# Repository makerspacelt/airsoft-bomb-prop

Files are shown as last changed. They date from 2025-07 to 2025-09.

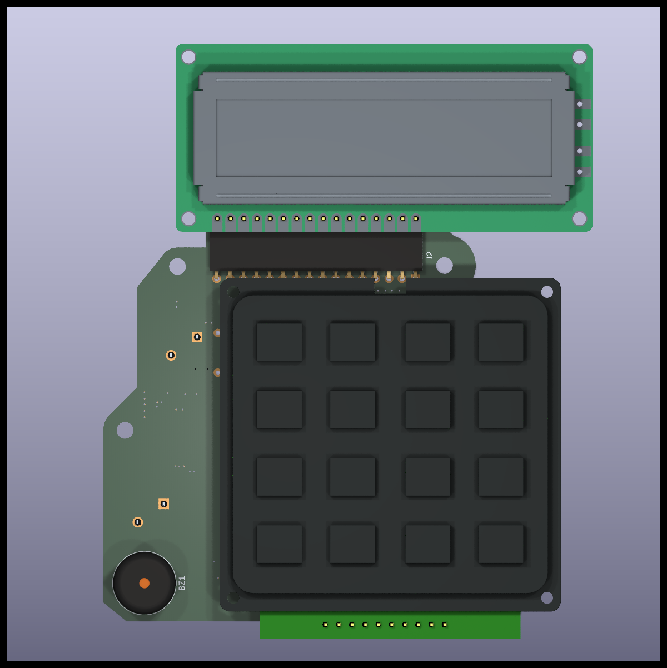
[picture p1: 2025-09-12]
hw/gen/img_pcb_3d_front.png

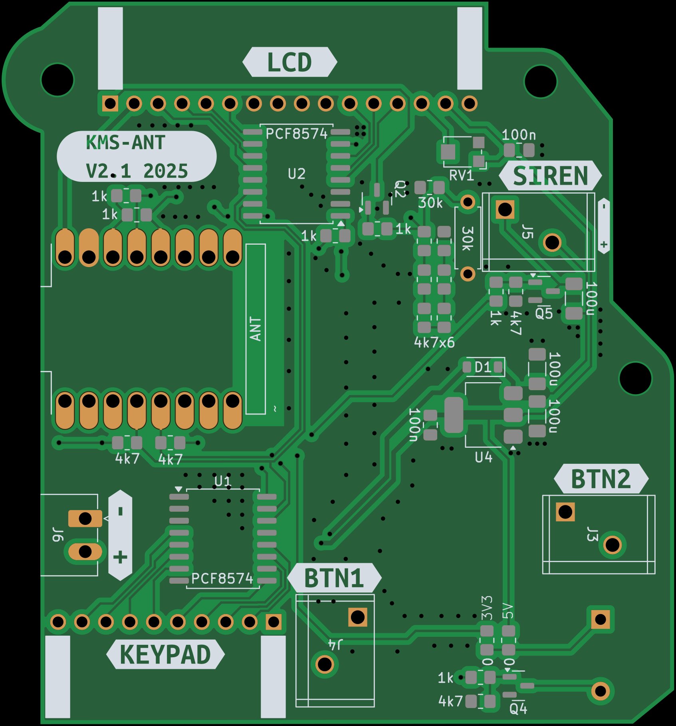
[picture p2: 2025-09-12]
hw/gen/img_pcb_2d_back_bare.jpg

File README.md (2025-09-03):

This is the source code of an Airsoft prop [KMS-ANT](http://armory.makerspace.lt) designed and sold by [Kaunas Makerspace](https://makerspace.lt).

This repository contains:

* [sw/](/sw) - ESPHome-based C++ software licensed under [GPL-3.0](/sw/LICENSE)
* [hw/](/hw) - PCB designed using KiCad and licensed under [CERN-OHL-S](/hw/LICENSE)

You can buy the product here: https://www.tindie.com/products/makerspacelt/airsoft-bomb-prop-kms-ant/

More information: http://armory.makerspace.lt/

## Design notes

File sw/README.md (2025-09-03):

This is the source code of an Airsoft prop [KMS-ANT](http://armory.makerspace.lt) designed and sold by [Kaunas Makerspace](https://makerspace.lt).

The code is licensed under GPL-3. If you modify this code and distribute it, then you are required to publish your changes under GPL-3 license as well.

# Building

```sh
# Build and flash esphome firmware, then open log monitoring
# (requires docker or podman for esphome)
$ make flash DEVICE=/dev/ttyACM0

# Build esphome firmware
# (requires docker or podman for esphome)
$ make fw

# Compile the pc build and run integration tests
# (requires the g++ compiler)
$ make test

# Compile the pc build and run it in interactive mode
# (requires the g++ compiler)
$ make interact

# Format project's C++ code using clang-format
# (requires the clang-format utility)
$ make format
```

# Code Structure

```
src-common/                → Shared code used across all platforms (ESP32 & PC)
  ├── utilities.hpp/cpp    → Helper functions (e.g., formatting time, progress bars)
  ├── globals.hpp          → Constants, key definitions, and global state (AntGlobals)
  ├── gm_*.hpp             → Game mode classes (each game is its own class)
  ├── gm_manager.hpp       → Main controller: manages game modes & user input.

src-pc/                    → PC-only code to simulate the game (for development/debugging)
  ├── main.cpp             → Entry point: runs interactive mode & test sequences
  └── mock_esphome.hpp     → Simulates ESP32 hardware (LCD, buttons, millis)

src-esphome/               → ESPHome firmware config
```

* All hardware is managed by [ESPHome](https://esphome.io/components/), as defined in `src-esphome/config.yaml`.
* All game logic is implemented in C++ in `src-common/*`.
* The game logic code communicates with ESPHome through globals, as defined in `src-esphome/esphome-entry.hpp`.
* There is a PC build for interactive and automated testing.

Normally in ESPHome you can call custom C++ code from lambdas defined in
`config.yaml` or from included C++ files. But calling ESPHome functions from
your custom C++ code is unsupported. So we try to keep this interaction to a
minimum. When we need to activate some hardware, we set an action state bitmask
(as defined in `src-common/globals.hpp`), then in ESPHome code we checked,
executed and reset the action state.

Game modes are implemented as classes with the following interface:
```cpp
class GameModeX {
public:
  // Constructor expects `AntGlobals antg` global state.
  AntGlobals &antg;
  GameModeX(AntGlobals &antg) : antg(antg) {}

  // Reset state and prepare for a new game.
  void init();

  // Render current game state to LCD.
  void display_update(esphome::lcd_base::LCDDisplay &disp);

  // Process user input and update game logic.
  void handle_key(unsigned char key);

  // Update time-based logic (timers, progress, events).
  void clock(uint32_t now, uint32_t delta);
};
```

# Tests

There is a custom test runner `src-pc/tests/test.sh` which executes all tests
defined in `src-pc/tests/test_*`. It captures the simulated LCD output, sends
key events and checks that the LCD output is as expected (as pre-recorded). Run
it using `make test`:

```sh
# Run all tests
$ make test

# Run only the test matching the "countdown" pcre regex pattern
$ make test TEST_PATTERN=countdown

# Record new state for the "test_countdown_game" test:
$ make test TEST_SAVE=1 TEST_PATTERN='^test_countdown_game$'

# Record new state for all tests (careful):
$ make test TEST_SAVE=1
```

The tests themselves are formatted like this: the first line is the event
sequence to be executed, separated by commas. All the other lines are expected
LCD display output. Allowed events are:
* `DELAY=n` - delay `n` number of ms
* All key chars defined with the `KEY_` prefix in `src-common/globals.hpp`
* `RED`, `RED_RELEASE`, `YELLOW`, `YELLOW_RELEASE` - yellow / red button press
  & release (always remember to release the red/yellow button after pressing it
  in the test).
* `RESET`, `C_LONG` - special key sequences.

# Engineering mode

There is a special test mode to test all keypad keys & red/yellow buttons. You
can access it by entering the Settings menu and pressing `5` on the keypad. It
will exit automatically after a few seconds of inactivity.

# Siren Levels

* LOW - 87 dB
* MEDIUM - 101 dB
* HIGH - 114 dB

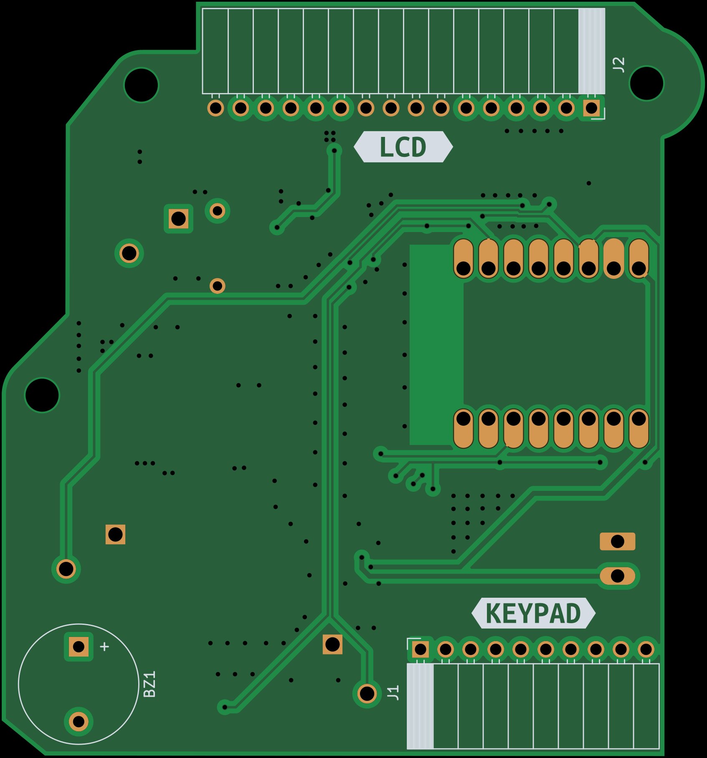
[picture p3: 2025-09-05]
hw/gen/img_pcb_2d_front_bare.jpg

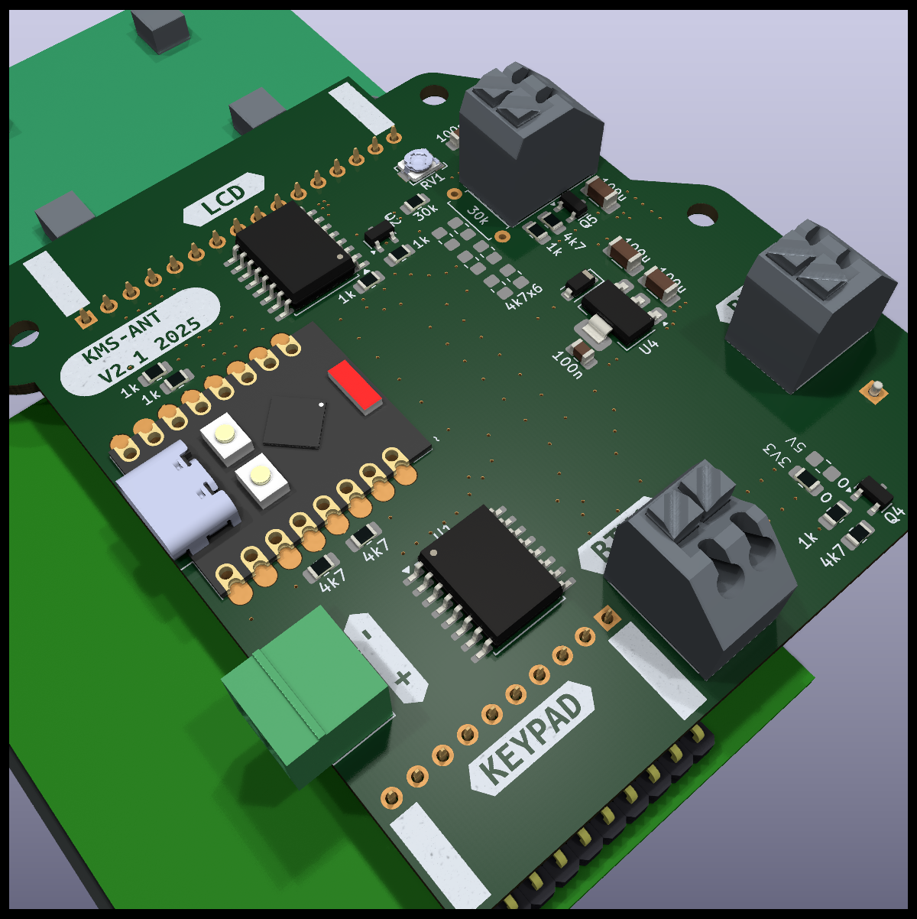
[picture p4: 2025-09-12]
hw/gen/img_pcb_3d_main.png

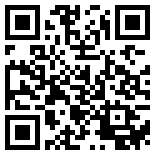
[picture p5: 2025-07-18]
hw/gen/qr_link.png

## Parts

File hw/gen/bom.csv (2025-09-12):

Row | Description | Part | References | Value | Footprint | Quantity Per PCB | Status | Datasheet | MPN | Sim.Device | Sim.Pins
1 | Buzzer, polarized | Buzzer | BZ1 | Buzzer | Buzzer_12x9.5RM7.6 | 1 |  | ~
2 | Unpolarized capacitor | C | C1,C3 | 100n | C_0805_2012Metric_Pad1.18x1.45mm_HandSolder | 2 |  | ~ | C49678
3 | Unpolarized capacitor | C | C2,C4,C5 | 100u | C_1206_3216Metric_Pad1.33x1.80mm_HandSolder | 3 |  | ~ | C7432784
4 | Diode | D | D1 | D | D_SOD-123 | 1 |  | ~ | C8598 | D | 1=K 2=A
5 | Generic connector, single row, 01x02, script generated (kicad-library-utils/schlib/autogen/connector/) | Conn_01x02 | J3,J4,J5 | BTN_R | HIWA 250-21-2G | 3 |  | ~
6 | Generic connector, single row, 01x02, script generated | Conn_01x02_Socket | J6 | Conn_01x02_Socket | PhoenixContact_MC_1,5_2-G-3.5_1x02_P3.50mm_Horizontal_with_plug | 1 |  | ~
7 | Generic connector, single row, 01x10, script generated | Conn_01x10_Pin | J1 | Conn_01x10_Pin | keypad | 1 |  | ~
8 | Generic connector, single row, 01x10, script generated | Conn_01x10_Socket | J8 | Conn_01x10_Socket | PinHeader_1x10_P2.54mm_Horizontal | 1 |  | ~
9 | Generic connector, single row, 01x16, script generated | Conn_01x16_Pin | J2 | Conn_01x16_Pin | screen | 1 |  | ~
10 | Generic connector, single row, 01x16, script generated | Conn_01x16_Socket | J7 | Conn_01x16_Socket | PinHeader_1x16_P2.54mm_Horizontal | 1 |  | ~
11 | 30V Vds, 5.7A Id, N-Channel MOSFET, SOT-23 | AO3400A | Q2,Q4,Q5 | AO3400A | SOT-23 | 3 |  | http://www.aosmd.com/pdfs/datasheet/AO3400A.pdf | C8545
12 | Resistor | R | R20 | 0 | R_0805_2012Metric_Pad1.20x1.40mm_HandSolder | 1 |  | ~ | C17477
13 | Resistor | R | R2,R3,R6,R7,R8,R9 | 1k | R_0805_2012Metric_Pad1.20x1.40mm_HandSolder | 6 |  | ~ | C17513
14 | Resistor | R | R4,R5,R10,R11 | 4k7 | R_0805_2012Metric_Pad1.20x1.40mm_HandSolder | 4 |  | ~ | C17673
15 | Resistor | R | R18 | 30k | R_0805_2012Metric_Pad1.20x1.40mm_HandSolder | 1 |  | ~ | C17621
16 | Potentiometer | R_Potentiometer | RV1 | 10k | Potentiometer_Bourns_TC33X_Vertical | 1 |  | ~ | C719176
17 | 1.5A 35V Adjustable Linear Regulator, SOT-223 | LM317_SOT-223 | U4 | LM317_SOT-223 | SOT-223-3_TabPin2 | 1 |  | http://www.ti.com/lit/ds/symlink/lm317.pdf | C6187
18 | 8 Bit Port/Expander to I2C Bus, DIP/SOIC-16 | PCF8574 | U1,U2 | PCF8574 | SOIC-16W_7.5x10.3mm_P1.27mm | 2 |  | http://www.nxp.com/docs/en/data-sheet/PCF8574_PCF8574A.pdf | C7605
19 | https://pricing.snapeda.com/parts/ESP32-C3%20SuperMini_TH/Espressif%20Systems/view-part?ref=eda Check availability | ESP32-C3_SUPERMINI | U3 | ~ | MODULE_ESP32-C3_SUPERMINI | 1

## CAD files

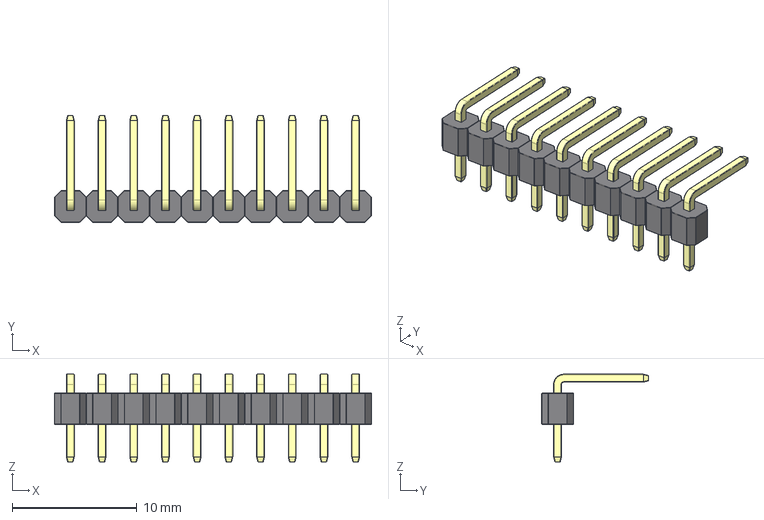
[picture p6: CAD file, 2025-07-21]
hw/airsoft_bomb_v2/3d/header_R1-01x10_P2.54_horizontal_R1.step
25.4 x 8.54 x 7.02 mm
Conductor x 10
Plastic x 10

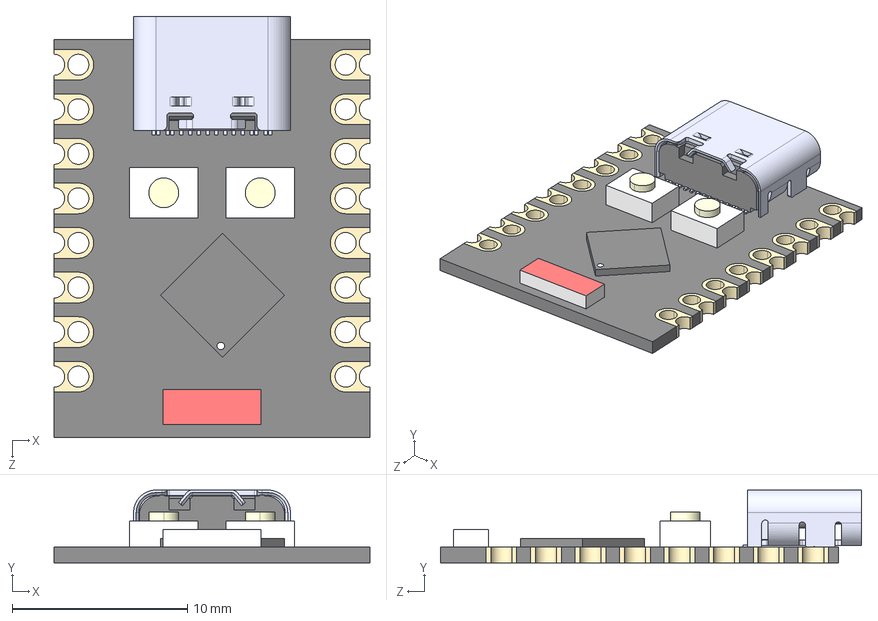
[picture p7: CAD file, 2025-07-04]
hw/airsoft_bomb_v2/3d/snapmagic/ESP32-C SuperMini/ESP32-C3 SuperMini_TH--3DModel-STEP-56544.STEP
18.0 x 4.16 x 24.0 mm
Board c3mini
USB C
components (other)^ESP32-C3 SuperMini

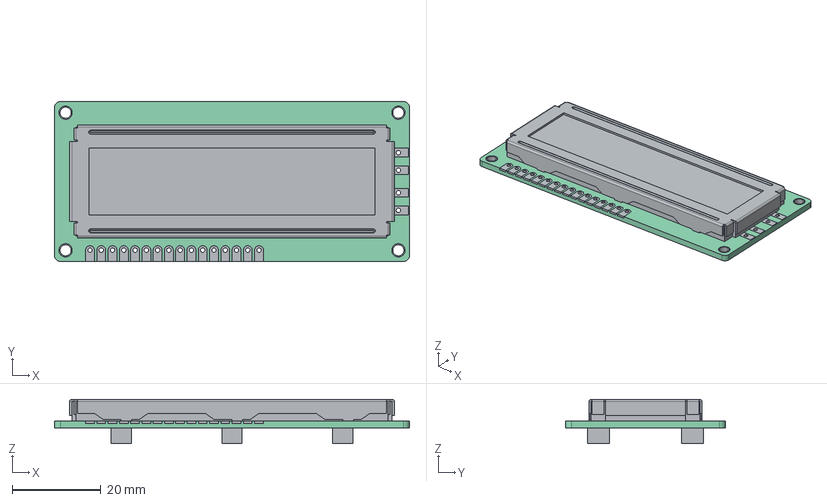
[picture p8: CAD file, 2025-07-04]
hw/airsoft_bomb_v2/3d/snapmagic/LCD1602/LCD1602.step
80.0 x 36.0 x 10.0 mm
LCD1636 (Mirror #1)
LCD1636 (Mirror #1)001
LCD1636 (Mirror #1)002
LCD1636 (Mirror #1)003
LCD1636 (Mirror #1)004
LCD1636 (Mirror #1)005
LCD1636 (Mirror #1)006
LCD1636 (Mirror #1)007
LCD1636 (Mirror #1)008
LCD1636 (Mirror #1)009
LCD1636 (Mirror #1)010
LCD1636 (Mirror #1)011
LCD1636 (Mirror #1)012
LCD1636 (Mirror #1)013
LCD1636 (Mirror #1)014
LCD1636 (Mirror #1)015
LCD1636 (Mirror #1)016
LCD1636 (Mirror #1)017
LCD1636 (Mirror #1)018
LCD1636 (Mirror #1)019
LCD1636 (Mirror #1)020
LCD1636 (Mirror #1)021
LCD1636 (Mirror #1)022
LCD1636 (Mirror #1)023
LCD1636 (Mirror #1)024
LCD1636 (Mirror #1)025
LCD1636 (Mirror #1)026
LCD1636 (Mirror #1)027
LCD1636 (Mirror #1)028
LCD1636 (Mirror #1)029
LCD1636 (Mirror #1)030
LCD1636 (Mirror #1)031
LCD1636 (Mirror #1)032
LCD1636 (Mirror #1)033

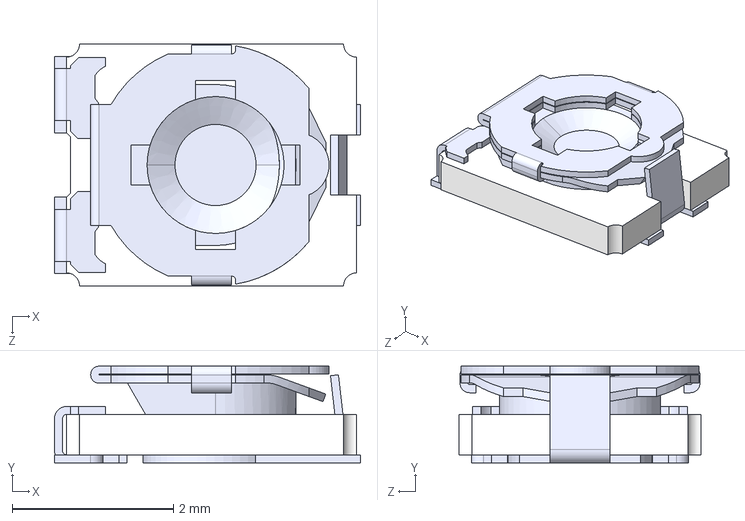
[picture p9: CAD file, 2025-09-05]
hw/airsoft_bomb_v2/3d/snapmagic/TC33X/TC33X-2-203E.STEP
3.80 x 1.20 x 3.00 mm

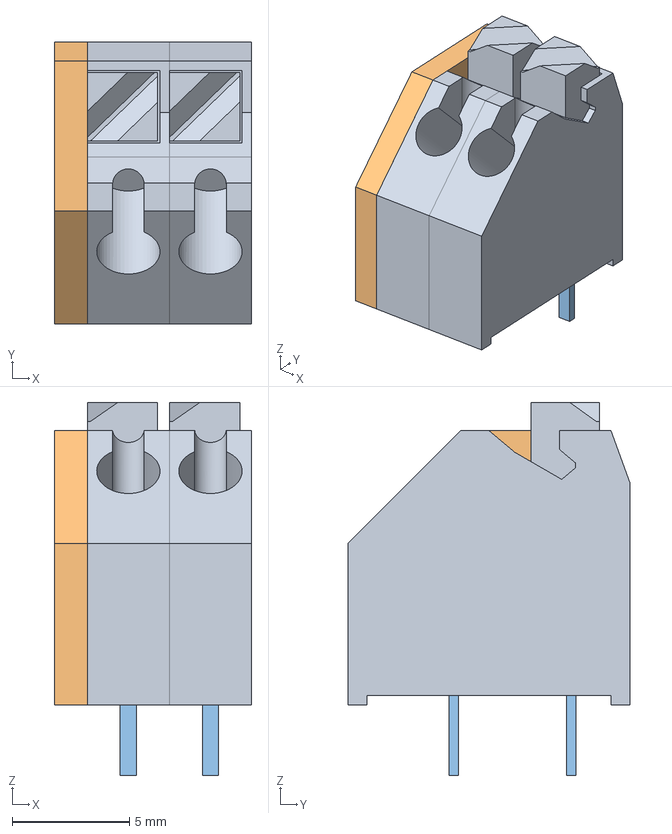
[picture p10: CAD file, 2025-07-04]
hw/models/HIWA 250-21-2G/HIWA 250-21-2G.FCStd
8.40 x 12.0 x 15.9 mm
main_part
left_wall
pins

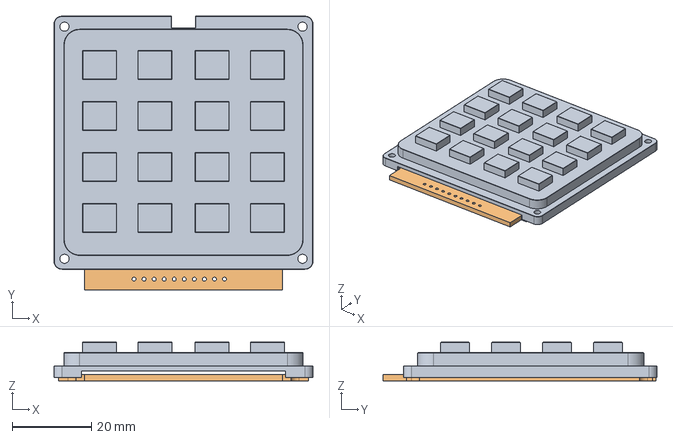
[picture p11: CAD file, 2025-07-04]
hw/models/keypad/keypad.FCStd
65.5 x 69.2 x 9.75 mm
plastic
pcb

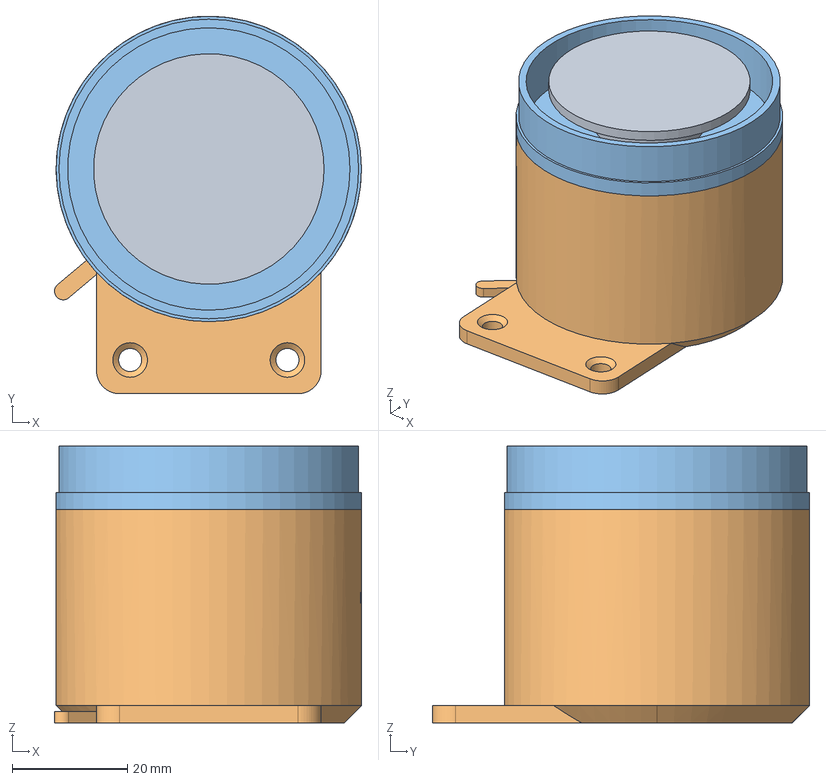
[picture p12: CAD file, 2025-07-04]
hw/models/siren/siren.FCStd
53.3 x 65.5 x 48.0 mm
red
black
white

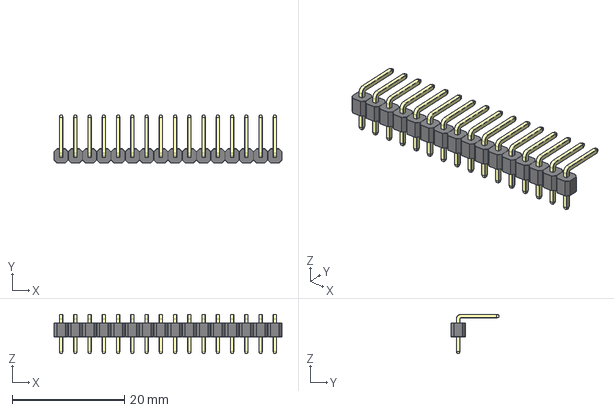
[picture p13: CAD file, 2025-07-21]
hw/airsoft_bomb_v2/3d/header_R1-01x16_P2.54_horizontal_R1.step
40.6 x 8.54 x 7.02 mm
Conductor x 16
Plastic x 16

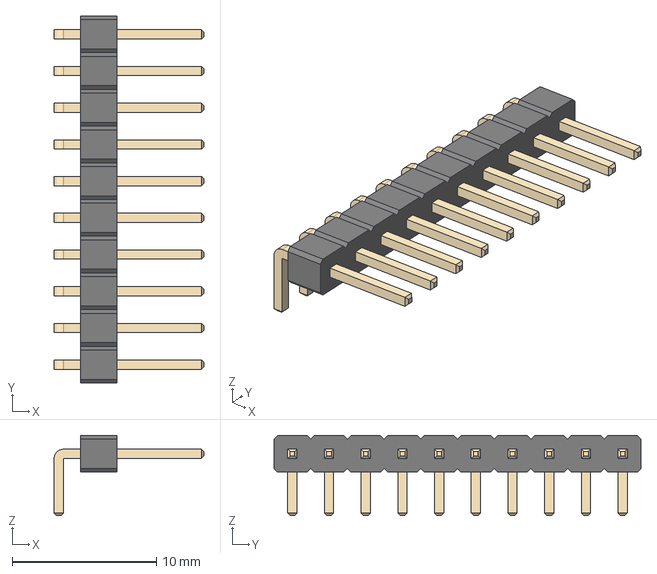
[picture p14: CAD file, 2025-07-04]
hw/airsoft_bomb_v2/3d/PinHeader_1x10_P254mm_Horizontal001.step
10.4 x 25.4 x 5.54 mm

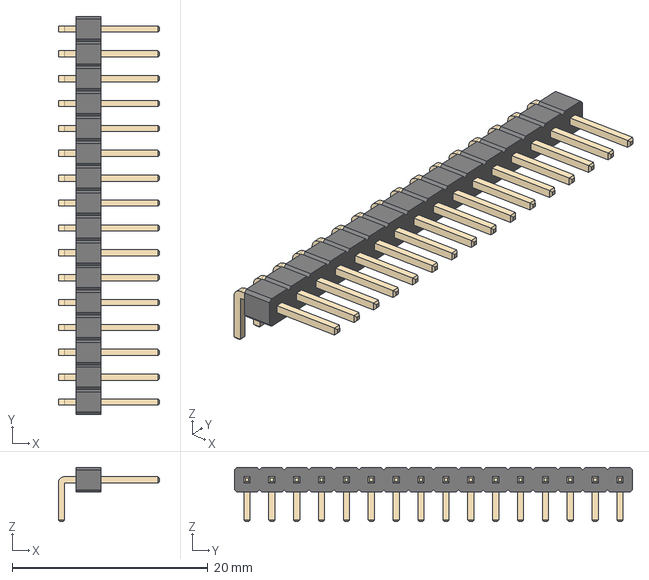
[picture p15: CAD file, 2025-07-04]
hw/airsoft_bomb_v2/3d/PinHeader_1x16_P254mm_Horizontal001.step
10.4 x 40.6 x 5.54 mm

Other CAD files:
hw/models/header/header_R1.FCStd
hw/airsoft_bomb_v2/3d/keypad.step
hw/airsoft_bomb_v2/3d/HIWA 250-21-2G.step

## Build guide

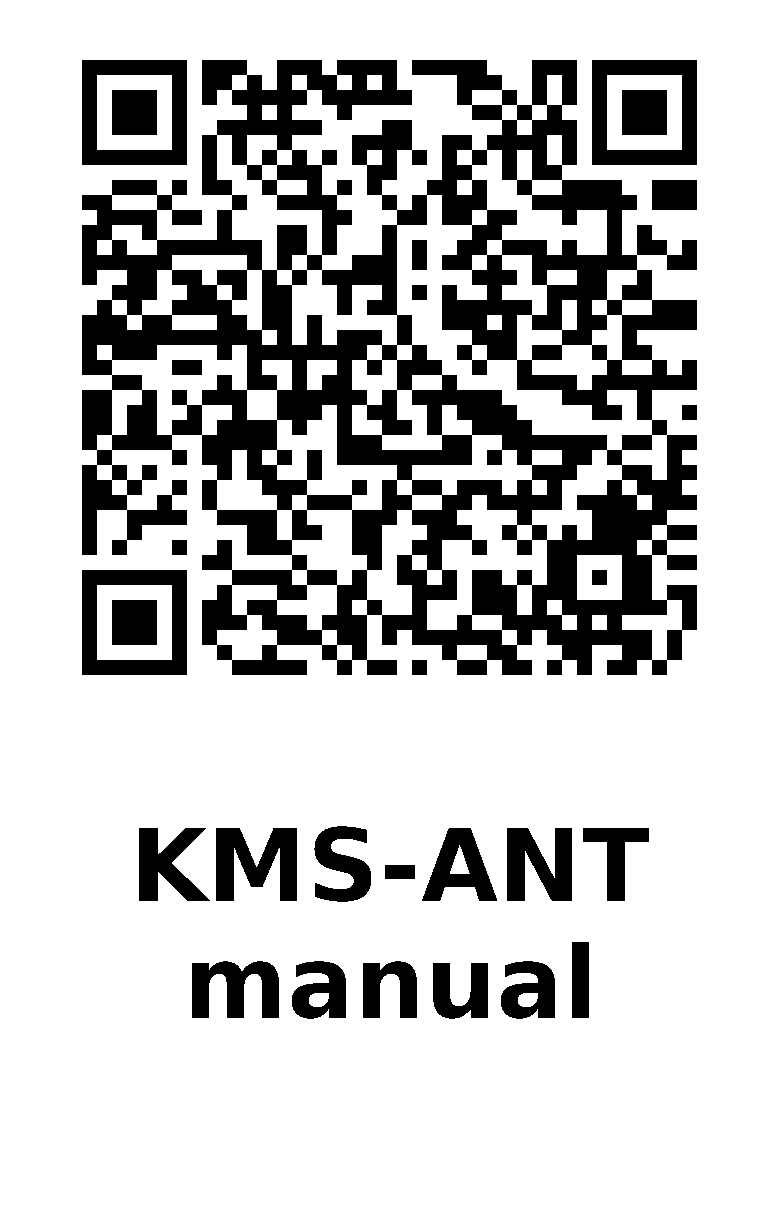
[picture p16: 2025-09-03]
manual-url-qr.png

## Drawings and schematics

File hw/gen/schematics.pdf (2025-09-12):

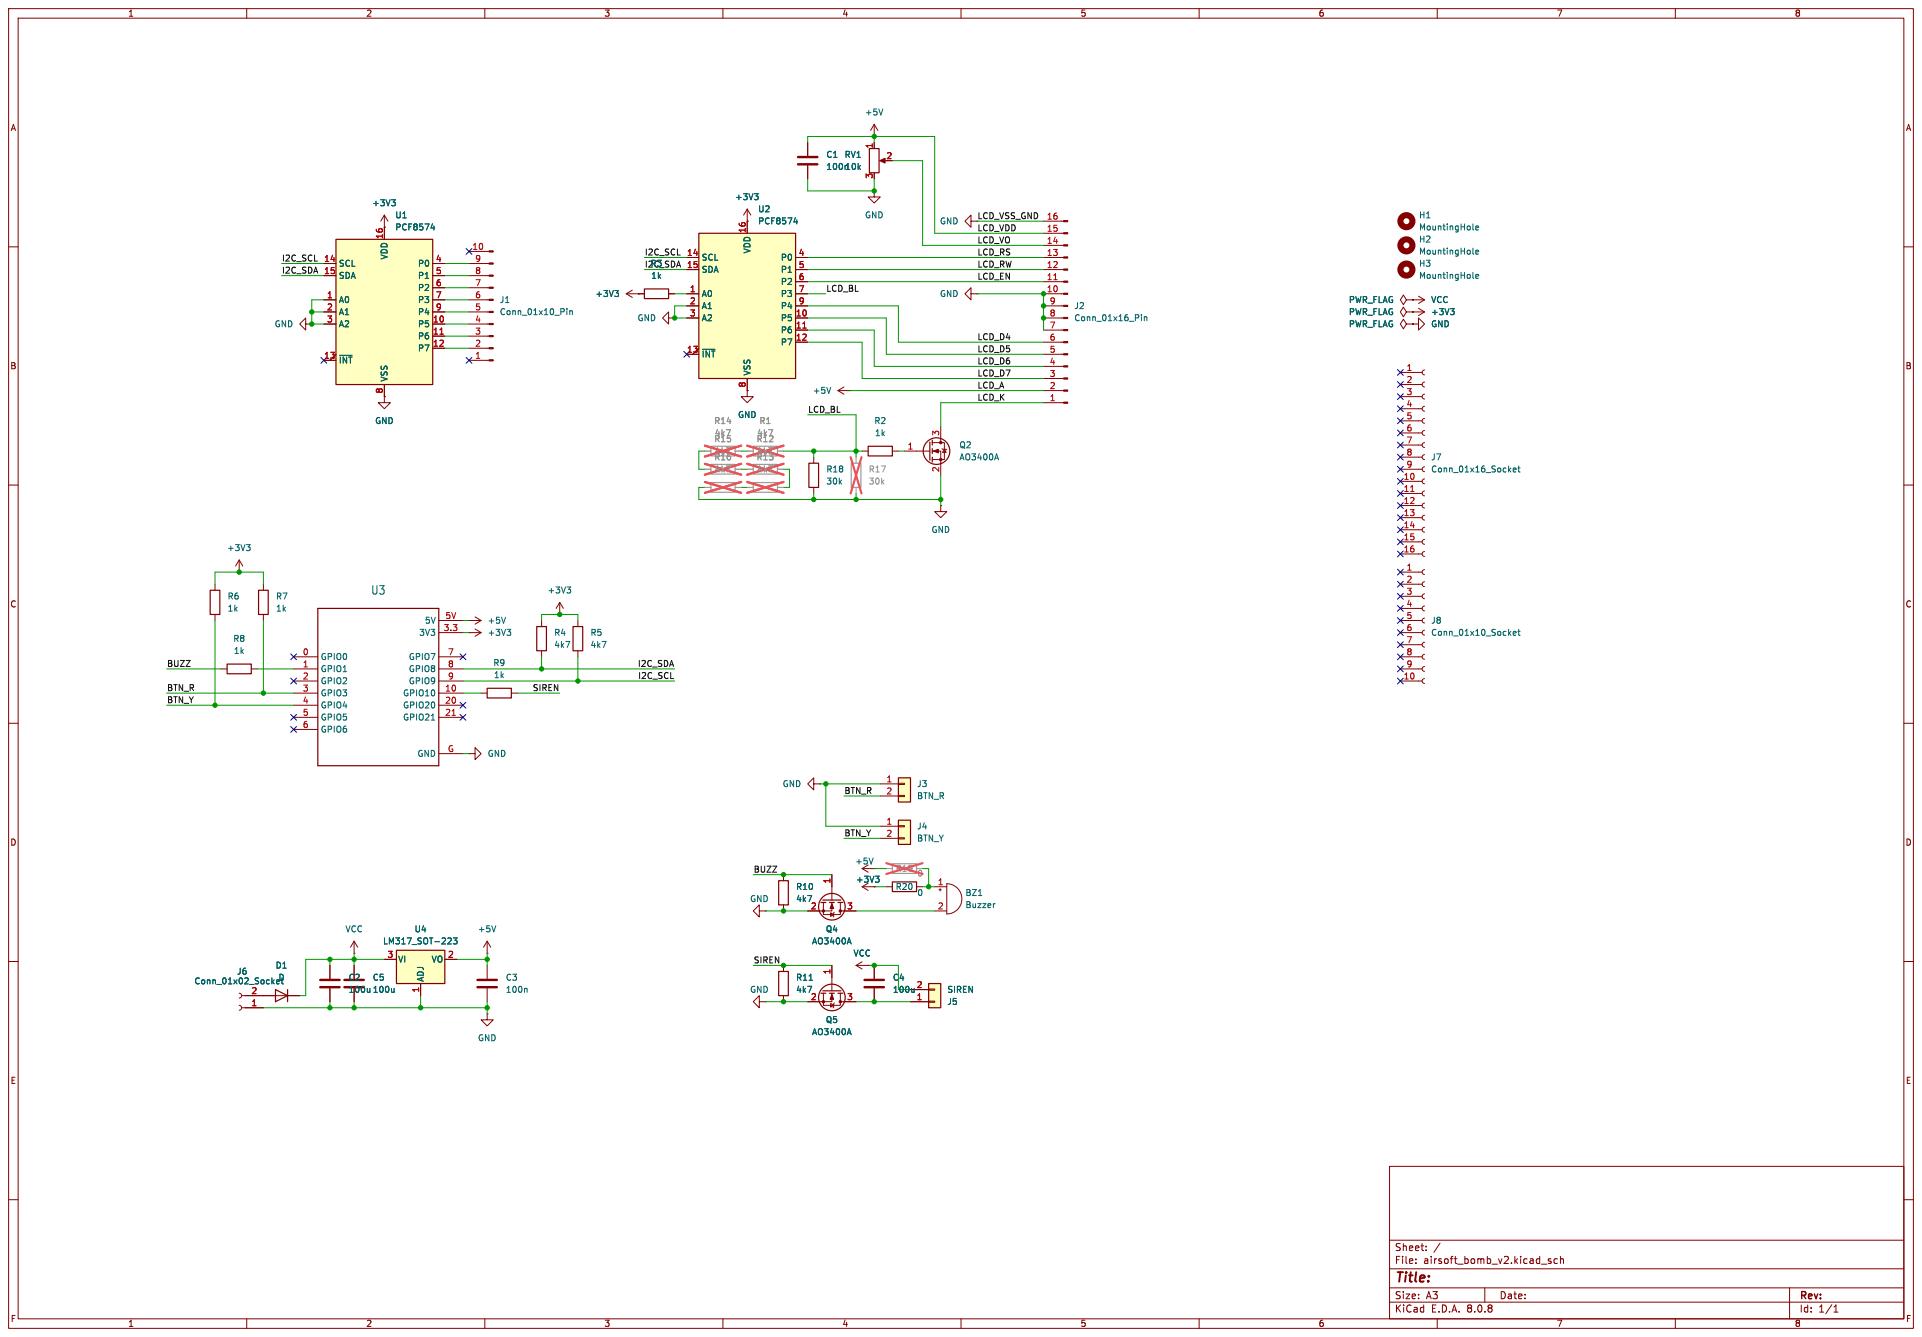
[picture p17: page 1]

Id: 1/1 Title: File: airsoft_bomb_v2.kicad_sch Sheet: /

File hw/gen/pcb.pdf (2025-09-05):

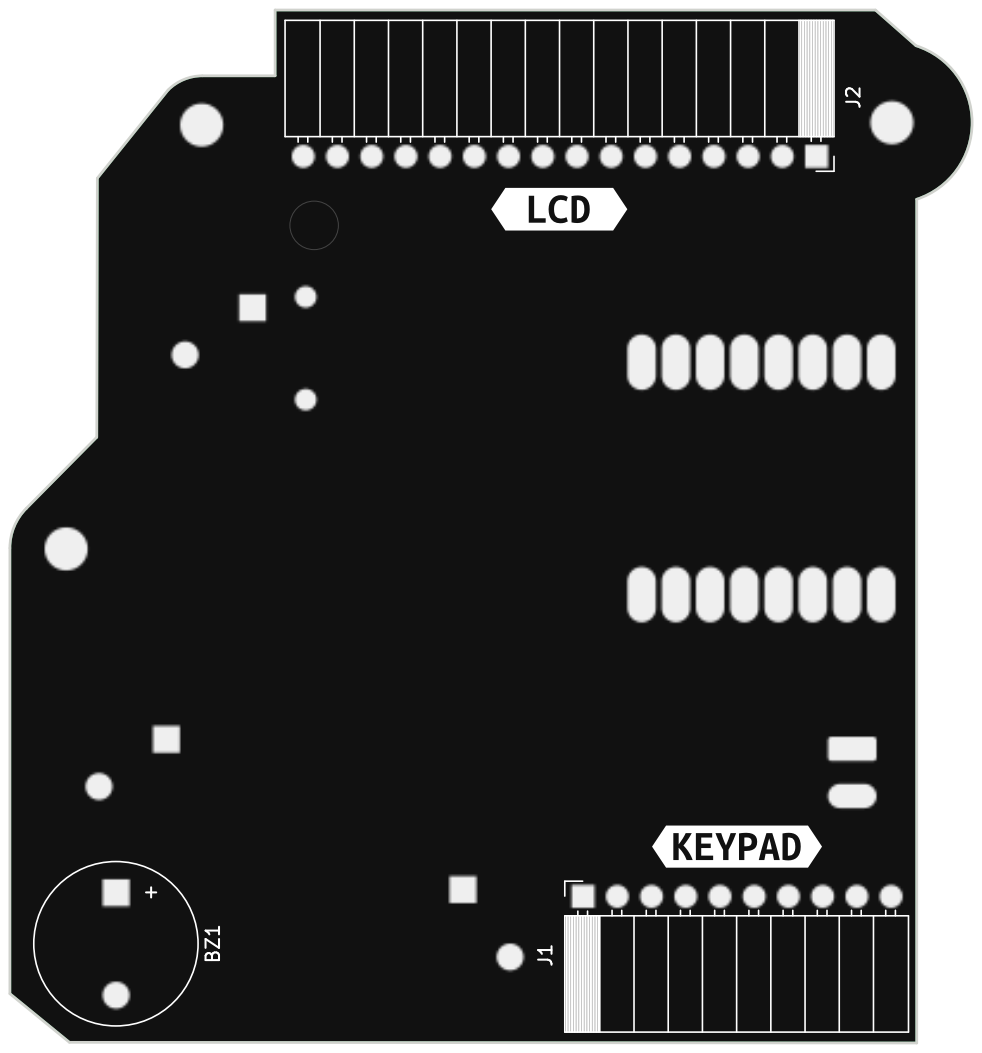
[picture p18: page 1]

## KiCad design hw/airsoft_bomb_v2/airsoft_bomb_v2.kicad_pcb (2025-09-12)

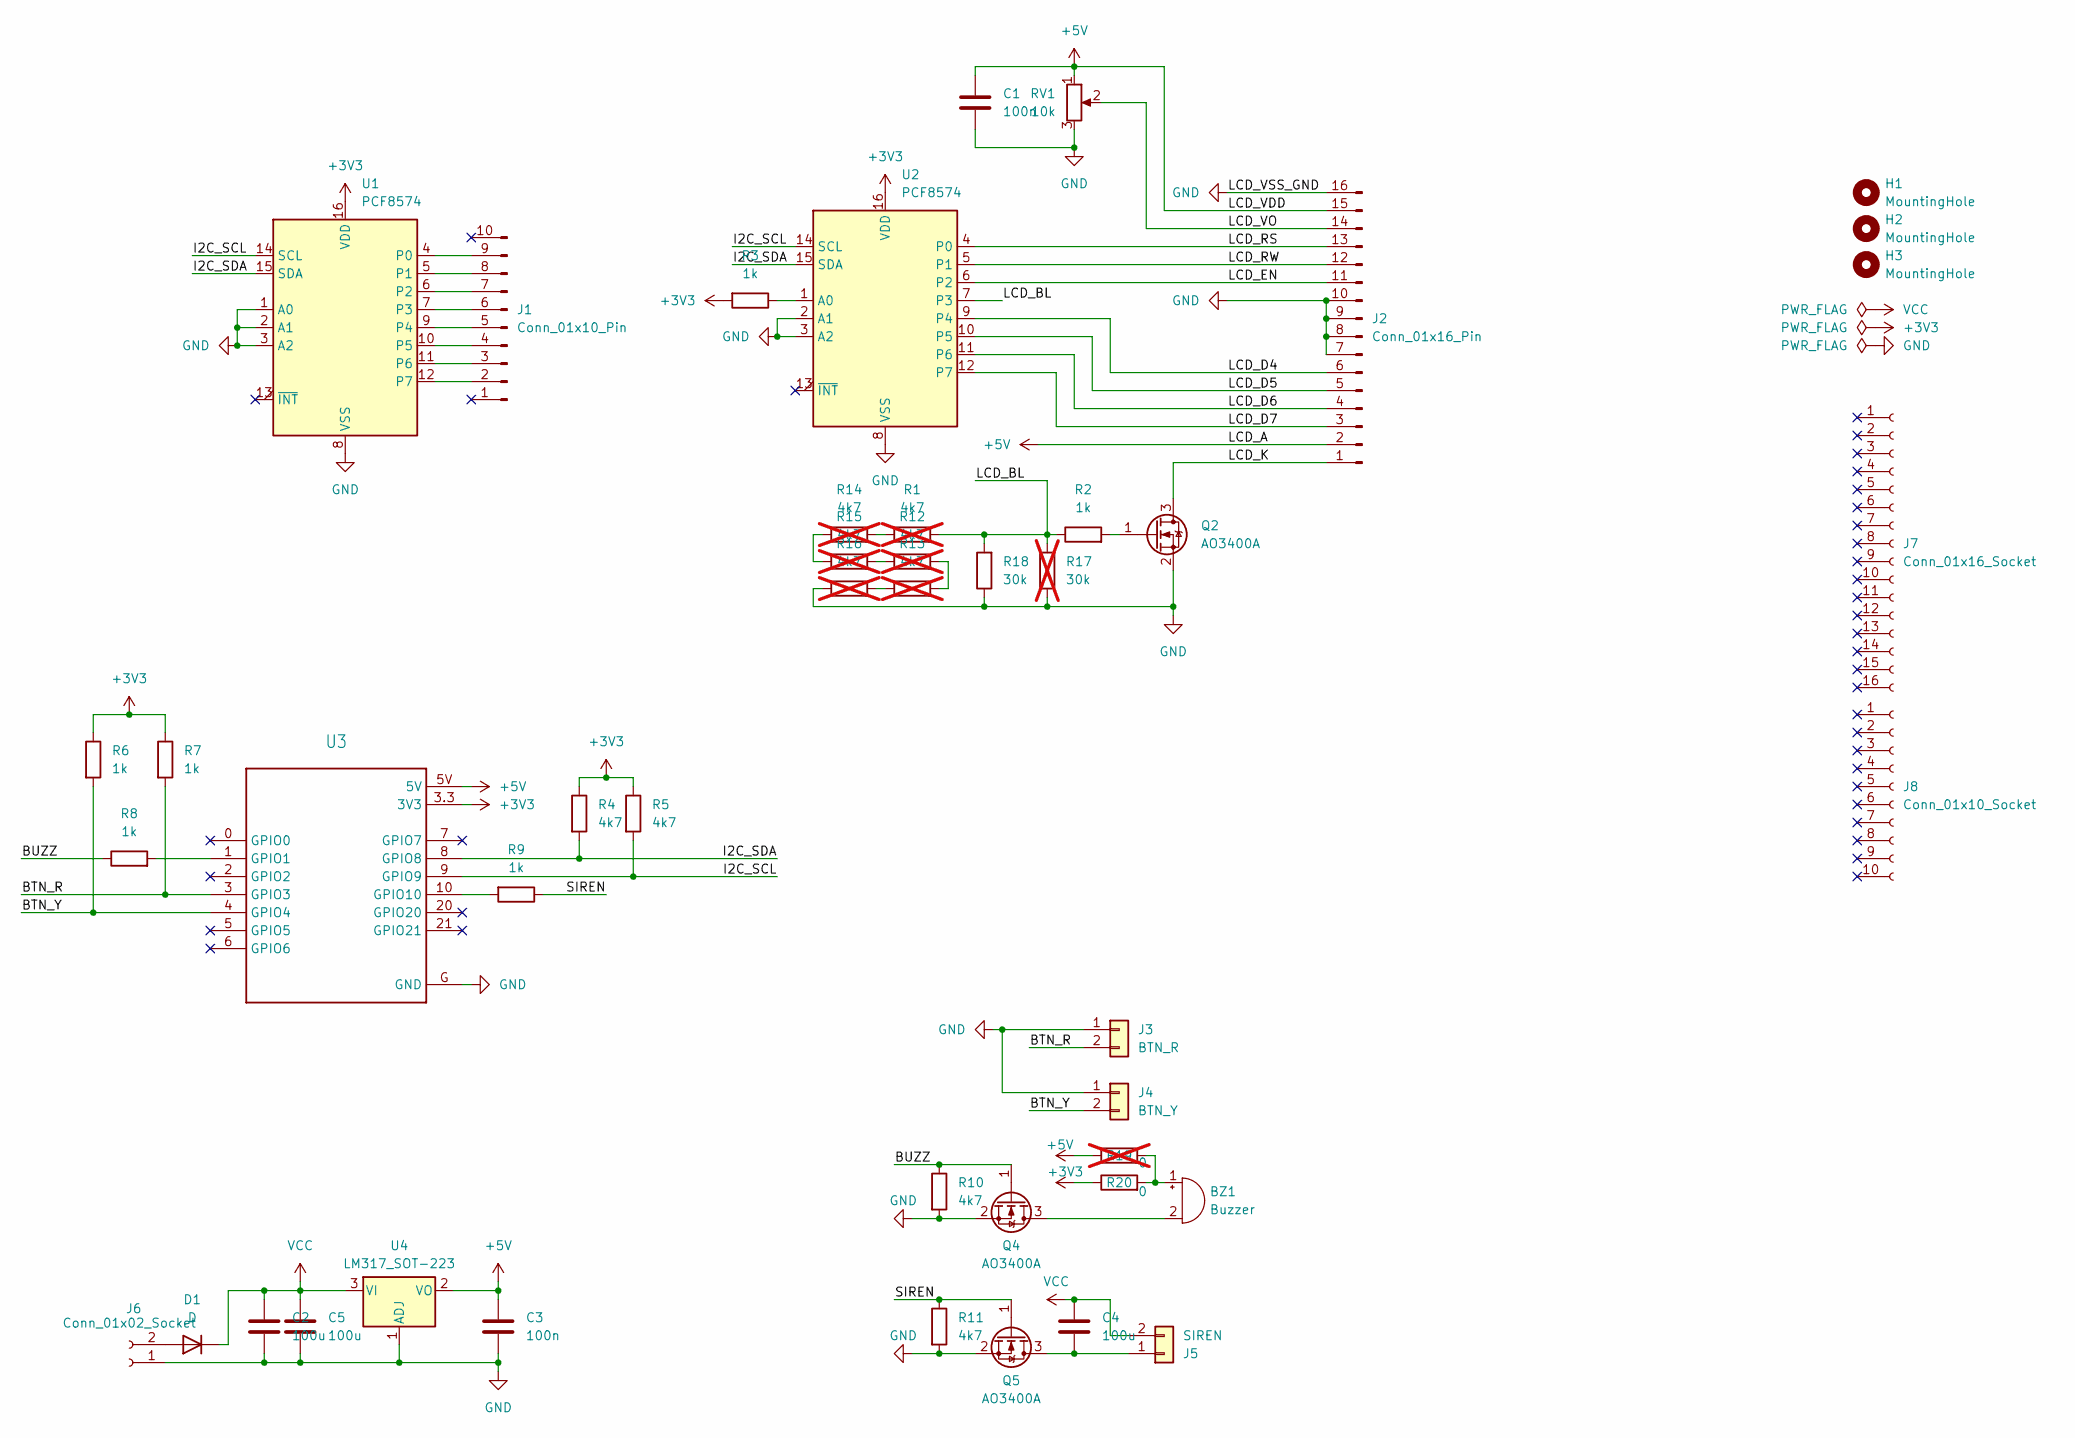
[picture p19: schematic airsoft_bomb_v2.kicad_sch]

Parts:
BZ1: Buzzer; Buzzer_12x9.5RM7.6
C1, C3: 100n; C_0805_2012Metric_Pad1.18x1.45mm_HandSolder; MPN C49678
C2, C4, C5: 100u; C_1206_3216Metric_Pad1.33x1.80mm_HandSolder; MPN C7432784
D1: D; D_SOD-123; MPN C8598
H1, H2, H3: MountingHole; MountingHole_3.2mm_M3
J1: Conn_01x10_Pin; keypad
J2: Conn_01x16_Pin; screen
J3: BTN_R; HIWA 250-21-2G
J4: BTN_Y; HIWA 250-21-2G
J5: SIREN; HIWA 250-21-2G
J6: Conn_01x02_Socket; PhoenixContact_MC_1,5_2-G-3.5_1x02_P3.50mm_Horizontal_with_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
J7: Conn_01x16_Socket; PinHeader_1x16_P2.54mm_Horizontal
J8: Conn_01x10_Socket; PinHeader_1x10_P2.54mm_Horizontal
Q2, Q4, Q5: AO3400A; SOT-23; MPN C8545
R1, R12, R13, R14, R15, R16: 4k7; R_0805_2012Metric_Pad1.20x1.40mm_HandSolder; MPN C17673; not fitted
R2, R3, R6, R7, R8, R9: 1k; R_0805_2012Metric_Pad1.20x1.40mm_HandSolder; MPN C17513
R4, R5, R10, R11: 4k7; R_0805_2012Metric_Pad1.20x1.40mm_HandSolder; MPN C17673
R17: 30k; R_Axial_DIN0207_L6.3mm_D2.5mm_P7.62mm_Horizontal; not fitted
R18: 30k; R_0805_2012Metric_Pad1.20x1.40mm_HandSolder; MPN C17621
R19: 0; R_0805_2012Metric_Pad1.20x1.40mm_HandSolder; MPN C17477; not fitted
R20: 0; R_0805_2012Metric_Pad1.20x1.40mm_HandSolder; MPN C17477
RV1: 10k; Potentiometer_Bourns_TC33X_Vertical; MPN C719176
U1, U2: PCF8574; SOIC-16W_7.5x10.3mm_P1.27mm; MPN C7605
U3: MODULE_ESP32-C3_SUPERMINI
U4: LM317_SOT-223; SOT-223-3_TabPin2; MPN C6187

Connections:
+3V3: R3.2, R4.1, R5.1, R6.1, R7.1, R20.1, U1.16 (VDD), U2.16 (VDD), U3.3.3 (3V3)
+5V: C1.1, C3.1, J2.2, J2.15, R19.1, RV1.1, U3.5V, U4.2 (VO)
/BTN_R: J3.2, R7.2, U3.3 (GPIO3)
/BTN_Y: J4.2, R6.2, U3.4 (GPIO4)
/BUZZ: Q4.1 (G), R8.1, R10.1
/I2C_SCL: R5.2, U1.14 (SCL), U2.14 (SCL), U3.9 (GPIO9)
/I2C_SDA: R4.2, U1.15 (SDA), U2.15 (SDA), U3.8 (GPIO8)
/LCD_BL: R1.2, R2.1, R17.2, R18.2, U2.7 (P3)
/LCD_D4: J2.6, U2.9 (P4)
/LCD_D5: J2.5, U2.10 (P5)
/LCD_D6: J2.4, U2.11 (P6)
/LCD_D7: J2.3, U2.12 (P7)
/LCD_EN: J2.11, U2.6 (P2)
/LCD_K: J2.1, Q2.3 (D)
/LCD_RS: J2.13, U2.4 (P0)
/LCD_RW: J2.12, U2.5 (P1)
/LCD_VO: J2.14, RV1.2
/SIREN: Q5.1 (G), R9.1, R11.1
GND: C1.2, C2.2, C3.2, C5.2, J2.7, J2.8, J2.9, J2.10, J2.16, J3.1, J4.1, J6.1, Q2.2 (S), Q4.2 (S), Q5.2 (S), R10.2, R11.2, R16.1, R17.1, R18.1, RV1.3, U1.1 (A0), U1.2 (A1), U1.3 (A2), U1.8 (VSS), U2.2 (A1), U2.3 (A2), U2.8 (VSS), U3.G (GND), U4.1 (ADJ)
unnamed: BZ1.1 (+), R19.2, R20.2
unnamed: BZ1.2 (-), Q4.3 (D)
unnamed: D1.2 (A), J6.2
unnamed: J1.2, U1.12 (P7)
unnamed: J1.3, U1.11 (P6)
unnamed: J1.4, U1.10 (P5)
unnamed: J1.5, U1.9 (P4)
unnamed: J1.6, U1.7 (P3)
unnamed: J1.7, U1.6 (P2)
unnamed: J1.8, U1.5 (P1)
unnamed: J1.9, U1.4 (P0)
unnamed: C4.2, J5.1, Q5.3 (D)
unnamed: Q2.1 (G), R2.2
unnamed: R1.1, R14.2
unnamed: R12.1, R15.2
unnamed: R12.2, R13.2
unnamed: R13.1, R16.2
unnamed: R14.1, R15.1
unnamed: R3.1, U2.1 (A0)
unnamed: R8.2, U3.1 (GPIO1)
unnamed: R9.2, U3.10 (GPIO10)
VCC: C2.1, C4.1, C5.1, D1.1 (K), J5.2, U4.3 (VI)

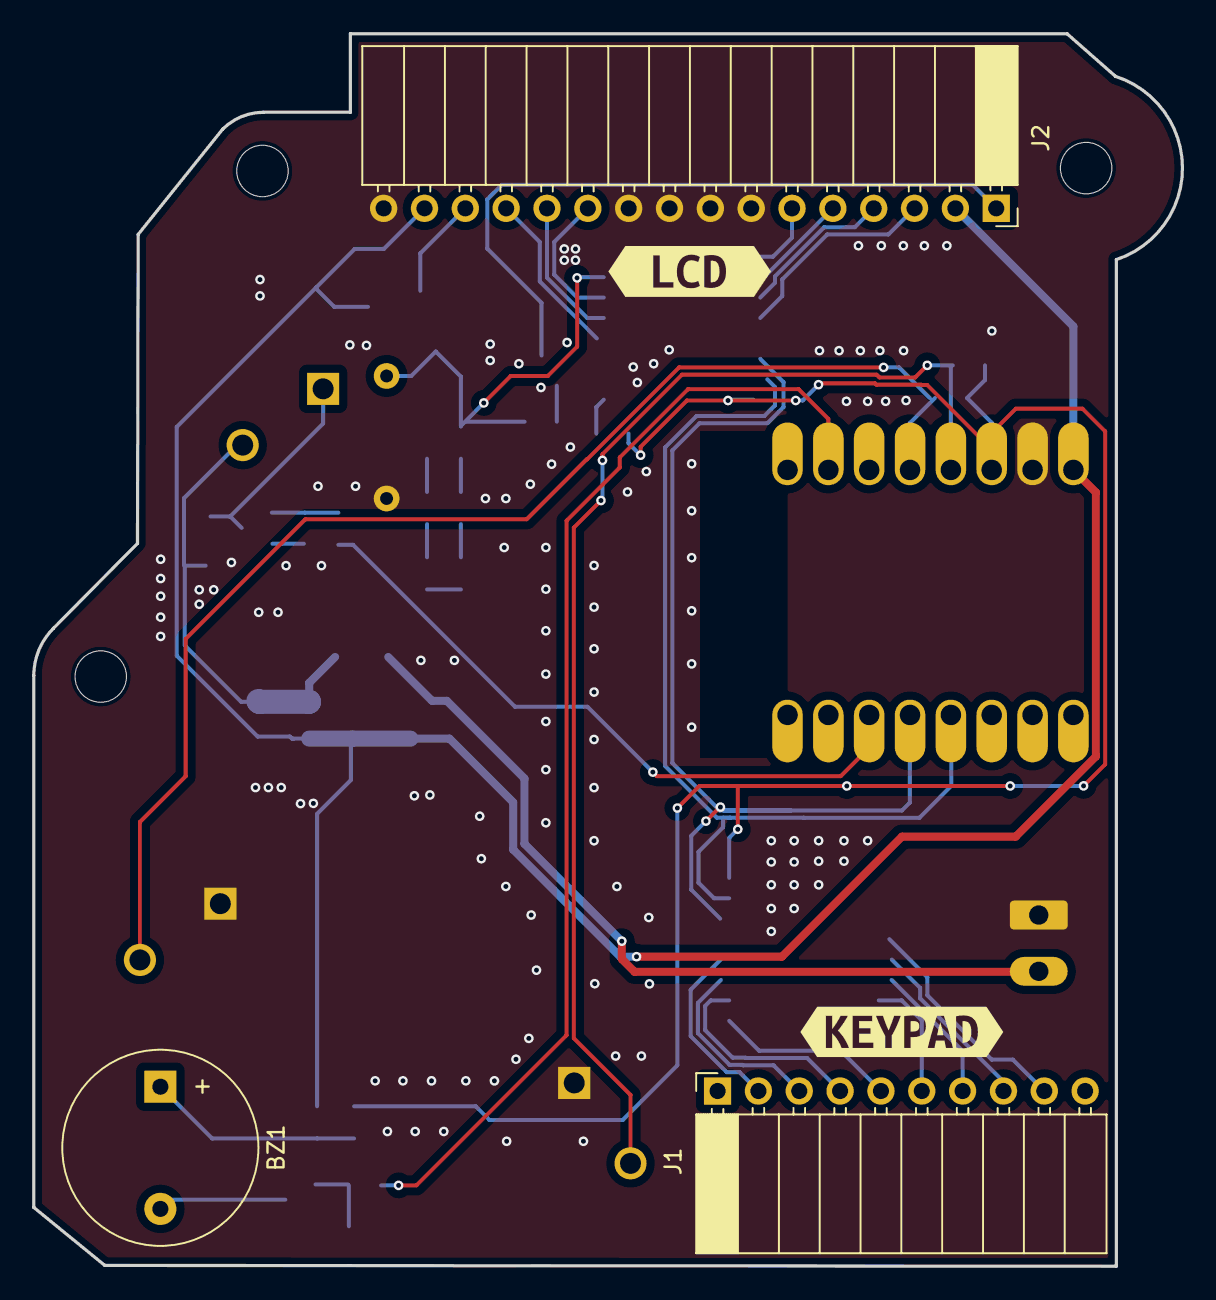
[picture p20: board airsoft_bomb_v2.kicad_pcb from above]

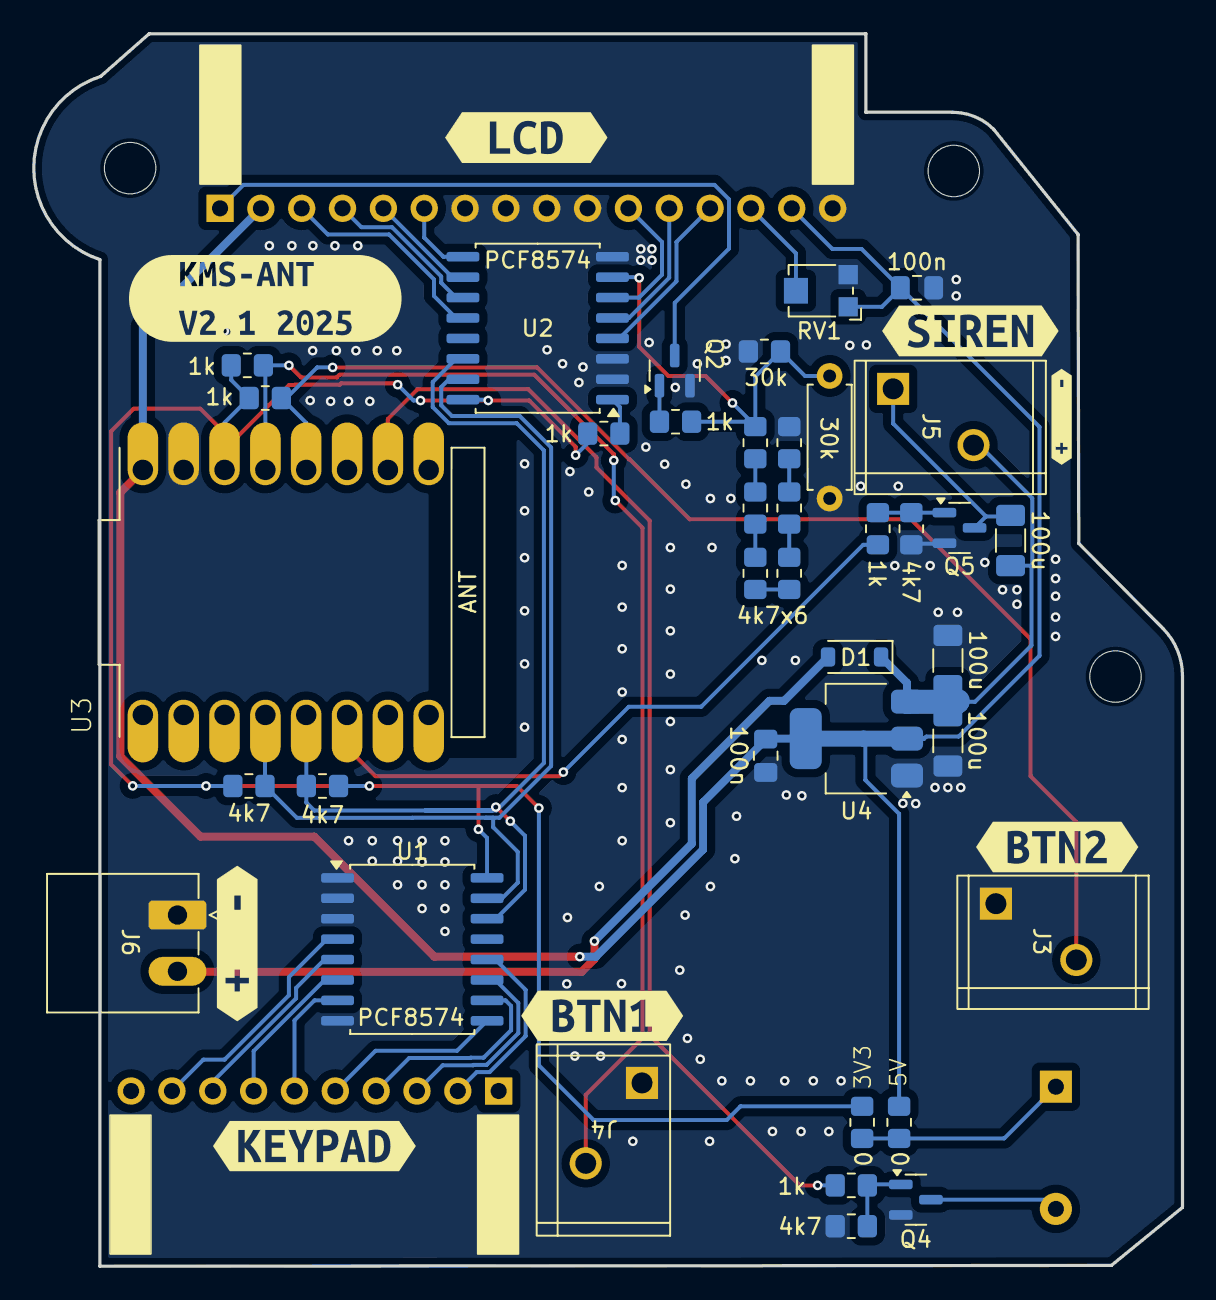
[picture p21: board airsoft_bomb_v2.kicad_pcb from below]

Board: 2 copper layers, 71.4 x 76.7 mm, 54 parts (49 on the bottom side), 41 nets.

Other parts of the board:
kibuzzard-67E6FC9B, kibuzzard-67E6FC9B#2: G***; kibuzzard-67E6FC9B
kibuzzard-67E6FC15: G***; kibuzzard-67E6FC15
kibuzzard-67E6FC26: G***; kibuzzard-67E6FC26
kibuzzard-67E6FC63, kibuzzard-67E6FC63#2: G***; kibuzzard-67E6FC63
kibuzzard-67E6FCB3: G***; kibuzzard-67E6FCB3
kibuzzard-67E6FE86: G***; kibuzzard-67E6FE86
kibuzzard-687FD9CC: G***; kibuzzard-687FD9CC
kibuzzard-68963AB1: G***; kibuzzard-68963AB1

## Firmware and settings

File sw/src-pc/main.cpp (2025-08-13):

#ifndef ESPHOME_VERSION

#include <algorithm>
#include <sstream>
#include <string>
#include <termios.h>
#include <thread>
#include <unistd.h>

#include "../src-common/gm_manager.hpp"
#include "mock_esphome.hpp"

#define TICK_INTERACTIVE 50

// --- Display Mock ---

esphome::lcd_base::LCDDisplay my_display;

// --- Time Mock ---

uint32_t cur_millis = 1;
uint32_t esphome::millis() { return cur_millis; }

// --- Non-blocking keyboard input ---
struct termios oldt, newt;

void set_unbuffered_input() {
  tcgetattr(STDIN_FILENO, &oldt);
  newt = oldt;
  newt.c_lflag &= ~(ICANON | ECHO);
  newt.c_cc[VMIN] = 0;
  newt.c_cc[VTIME] = 0;
  tcsetattr(STDIN_FILENO, TCSANOW, &newt);
}

void restore_input_buffering() { tcsetattr(STDIN_FILENO, TCSANOW, &oldt); }

// --- Main Application ---

AntGlobals antg;
GameManager game_manager(antg);

void update_display() {
  game_manager.display_update(my_display);
  my_display.present();
}

void process_test_sequence(const std::string &sequence) {
  std::stringstream ss(sequence);
  std::string token;

  update_display();

  while (std::getline(ss, token, ',')) {
    // Convert token to uppercase for case-insensitivity
    std::transform(token.begin(), token.end(), token.begin(), [](unsigned char c) { return std::toupper(c); });

    if (token.rfind("DELAY=", 0) == 0) {
      int delay_ms = std::stoi(token.substr(6));
      printf("[DELAY %d]\n", delay_ms);
      cur_millis += delay_ms;
      game_manager.clock(cur_millis, delay_ms);
    } else if (token.length() == 1) {
      printf("[KEY %s]\n", token.c_str());
      game_manager.handle_key(token[0]);
    } else {
      printf("[KEY %s]\n", token.c_str());
      if (token == "RED") {
        game_manager.handle_key(KEY_RED);
      } else if (token == "RED_RELEASE") {
        game_manager.handle_key(KEY_RED_RELEASE);
      } else if (token == "YELLOW") {
        game_manager.handle_key(KEY_YELLOW);
      } else if (token == "YELLOW_RELEASE") {
        game_manager.handle_key(KEY_YELLOW_RELEASE);
      } else if (token == "RESET") {
        game_manager.handle_key(KEY_RESET);
      } else if (token == "C_LONG") {
        game_manager.handle_key(KEY_C_LONG);
      } else {
        printf("ERROR: Unknown test token: %s\n", token.c_str());
      }
    }
    update_display();
  }
}

int main(int argc, char *argv[]) {
  set_unbuffered_input();
  atexit(restore_input_buffering);

  for (int i = 1; i < argc; ++i) {
    std::string arg = argv[i];
    if (arg == "--test" && i + 1 < argc) {
      std::string sequence = argv[++i];
      process_test_sequence(sequence);
      return 0; // Exit after sequence
    }
  }

  ESP_LOGI("main", "Starting interactive mode... Press 'q' to quit.");

  // Interactive loop
  while (true) {
    unsigned char key = 0;
    if (read(STDIN_FILENO, &key, 1) > 0) {
      switch (key) {
      case 'q':
      case 'Q': ESP_LOGI("main", "Exiting interactive mode."); return 0;
      case 'r': game_manager.handle_key(KEY_RED); break;
      case 'R': game_manager.handle_key(KEY_RED_RELEASE); break;
      case 'y': game_manager.handle_key(KEY_YELLOW); break;
      case 'Y': game_manager.handle_key(KEY_YELLOW_RELEASE); break;
      case 'x': game_manager.handle_key(KEY_RESET); break;
      case 'n': game_manager.handle_key(KEY_C_LONG); break;
      default:  game_manager.handle_key(std::toupper(key)); break;
      }
    }

    cur_millis += TICK_INTERACTIVE;
    game_manager.clock(esphome::millis(), TICK_INTERACTIVE);
    update_display();
    std::this_thread::sleep_for(std::chrono::milliseconds(100));
  }

  return 0;
}

#endif

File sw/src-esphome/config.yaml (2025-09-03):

#
# Board
#

esp32:
  board: esp32-c3-devkitm-1
  framework:
    type: esp-idf

#
# esphome core
#

external_components:
  - source:
      type: local
      path: mycomponents

esphome:
  name: ant
  name_add_mac_suffix: true
  includes:
    - ../src-common
    - esphome-entry.hpp
  on_boot:
    - then:
        lambda: |-
          id(siren).turn_on();
          id(siren).set_level(0);
          id(buzzer).turn_on();
          id(buzzer).set_level(0);
          antg.action_set_siren_level(id(g_siren_level), false);
  on_shutdown:
    - then:
        lambda: |-
          id(siren).turn_off();
          id(buzzer).turn_off();

logger:
  level: DEBUG

preferences:
  flash_write_interval: 10s

mdns:
  disabled: true

#
# OTA config
#

wifi:
  id: mywifi
  enable_on_boot: false

  ap:
    password: 100decibel
    ap_timeout: 10s

ota:
  - platform: web_server
    on_begin:
      then:
        - lambda: |-
            id(my_display).print(0, 0, "    Updating    ");
            id(my_display).print(0, 1, "    firmware    ");
    on_error:
      then:
        - lambda: |-
            id(my_display).print(0, 0,  "    Updating    ");
            id(my_display).printf(0, 1, "   Error %d    ", x);

web_server:
  port: 80
  index_html_include: ./index.html

#
# Prop hardware
#

globals:
  - id: g_siren_level # 1-9
    type: int
    restore_value: true
    initial_value: "9"

output:
  - platform: ledc
    pin: GPIO1
    id: buzzer
    frequency: 1000Hz

  - platform: ledc
    pin: GPIO10
    id: siren

binary_sensor:
  # RED button
  - platform: gpio
    pin: GPIO3
    id: btn_r
    filters:
      - invert:
    on_press:
      lambda: |-
        ESP_LOGI("Key", "on_press RED");
        game_manager.handle_key(KEY_RED);
        id(my_display).update();
    on_release:
      lambda: |-
        ESP_LOGI("Key", "on_release RED");
        game_manager.handle_key(KEY_RED_RELEASE);
        id(my_display).update();

  # YELLOW button
  - platform: gpio
    pin: GPIO4
    id: btn_y
    filters:
      - invert:
    on_press:
      lambda: |-
        ESP_LOGI("Key", "on_press YELLOW");
        game_manager.handle_key(KEY_YELLOW);
        id(my_display).update();
    on_release:
      lambda: |-
        ESP_LOGI("Key", "on_release YELLOW");
        game_manager.handle_key(KEY_YELLOW_RELEASE);
        id(my_display).update();

  # C long press handling for game restart
  - platform: matrix_keypad
    keypad_id: mykeypad
    id: key_c
    key: C
    on_press:
      lambda: |-
        game_manager.key_c_press_at = millis();
    on_release:
      lambda: |-
        game_manager.key_c_press_at = 0;

  # D long press handling for organizer game reset
  - platform: matrix_keypad
    keypad_id: mykeypad
    id: key_d
    key: D
    on_press:
      lambda: |-
        game_manager.hard_reset_press_at = millis();
    on_release:
      lambda: |-
        game_manager.hard_reset_press_at = 0;

  # * long press handling for organizer game reset
  - platform: matrix_keypad
    keypad_id: mykeypad
    id: key_star
    key: "*"
    on_press:
      lambda: |-
        game_manager.hard_reset_press_at = millis();
    on_release:
      lambda: |-
        game_manager.hard_reset_press_at = 0;

matrix_keypad:
  id: mykeypad
  rows:
    - pin:
        pcf8574: pcf8574_hub
        number: 0
    - pin:
        pcf8574: pcf8574_hub
        number: 1
    - pin:
        pcf8574: pcf8574_hub
        number: 2
    - pin:
        pcf8574: pcf8574_hub
        number: 3
  columns:
    - pin:
        pcf8574: pcf8574_hub
        number: 4
    - pin:
        pcf8574: pcf8574_hub
        number: 5
    - pin:
        pcf8574: pcf8574_hub
        number: 6
    - pin:
        pcf8574: pcf8574_hub
        number: 7
  keys: "D#0*C987B654A321"
  has_diodes: false
  on_key:
    - lambda: |-
        ESP_LOGI("Key", "on_key %c", x);
        game_manager.handle_key(x);
        id(my_display).update();

i2c:
  - id: bus_a
    sda: GPIO8
    scl: GPIO9
    frequency: 300kHz

pcf8574:
  - id: "pcf8574_hub"
    address: 0x20
    pcf8575: false
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

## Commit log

2025-07-04 pcb files
    [ESP32-C3 SuperMini_TH--3DModel-STEP-56544.STEP, HIWA 250-21-2G.FCStd, HIWA 250-21-2G.step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]
2025-07-15 Implement hard reset to main menu and fixed and fixed issue when after R/Y/* button press duration function was executed, the timer even though reset, but started counting again without needing anoth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
    [config.yaml]
2025-07-17 update pcb step file
2025-07-18 add kibot.sh and required fixes
    [_pos.csv, airsoft_bomb_v2--NPTH_map.gbr, airsoft_bomb_v2--PTH_map.gbr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]
2025-07-21 fix wrong header model fix pcb interferes with screen screw
    [airsoft_bomb_v2--NPTH_map.gbr, airsoft_bomb_v2--PTH_map.gbr, airsoft_bomb_v2-B_Cu.gbr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]
2025-07-22 mark creen/keypad connectors on other side of pcb mark siren +/-
    [airsoft_bomb_v2.kicad_pcb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]
2025-08-01 move siren pin to something that is not high on boot
    [airsoft_bomb_v2.kicad_pcb, airsoft_bomb_v2.kicad_sch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]
2025-08-01 move siren to gpio10, fix defusal bad code timer
    [config.yaml, gm_defusal.hpp]
2025-08-05 Add Back menu to all modes. Fix D key in settings.
    [gm_defusal.hpp, gm_domination.hpp, gm_manager.hpp]
2025-08-05 fix domination restart with C_LONG
    [gm_domination.hpp, gm_manager.hpp, main.cpp]
2025-08-05 defusal/buttons: add missing break after case to fix states
    [gm_defusal.hpp]
2025-08-05 defusal code: fix bomb_ms_remaining type
    [gm_defusal.hpp]
2025-08-05 defusal more fixes & add tests
    [gm_defusal.hpp]
2025-08-08 version silkscreen
    [airsoft_bomb_v2.kicad_pcb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]
2025-08-13 fix defusal game delay timer
    [gm_defusal.hpp]
2025-08-13 fix defusal bomb timer - it should not tick before it's armed
    [gm_defusal.hpp]
2025-08-13 do not buzz for C long press if it does no action and buzz on press during splashscreen
    [gm_manager.hpp]
2025-08-13 stop siren on reset and on C_LONG press
    [gm_defusal.hpp, gm_domination.hpp, gm_manager.hpp]
2025-08-13 do not override previous buzzer if it's already beeping
    (needed for respawn timer)
    [config.yaml]
2025-08-13 respawn timer: rename respawn->standby, duration->respawn
2025-08-13 defusal: fix countdown buzzer when armed
    [gm_defusal.hpp]
2025-08-13 makefile: print compiled firmware path
2025-09-03 test.sh: print number of tests ran, exit with error on test fails
2025-09-03 tests: add tests for respawn timer mode
2025-09-05 change potentiometer to smd
    [TC33X-2-203E.STEP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]
2025-09-12 add polarity protection diode on voltage input lcsc part numbers
    [airsoft_bomb_v2.kicad_pcb, airsoft_bomb_v2.kicad_sch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]
